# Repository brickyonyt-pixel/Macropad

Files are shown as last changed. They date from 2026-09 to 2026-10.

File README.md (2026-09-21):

# Macropad

A custom programmable macropad designed and built as part of my Hack Club Stardance project.

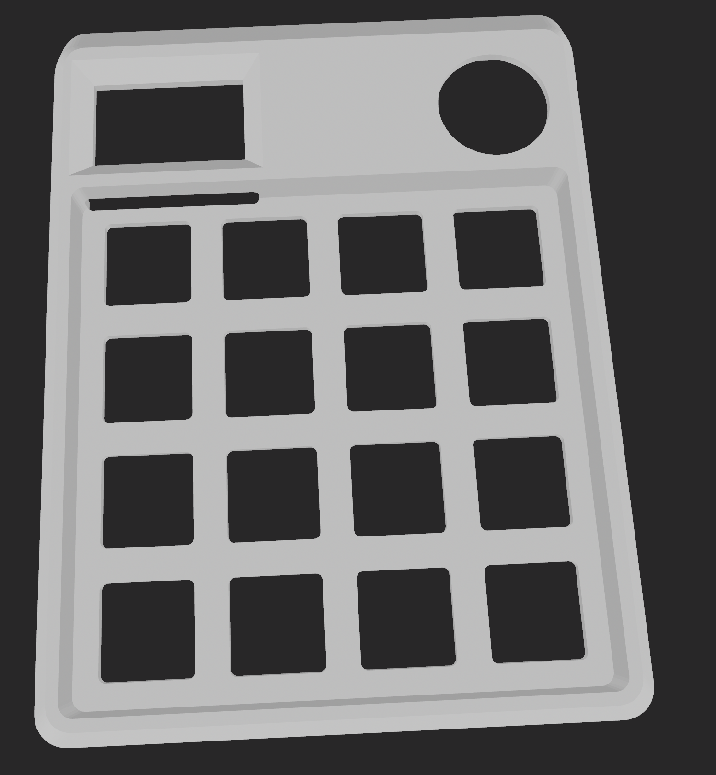
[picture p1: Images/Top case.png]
Macropad


## Overview

This project is a custom macropad designed to provide a compact way to use shortcuts and macros.

I designed the physical parts of the macropad around the PCB, including the top case, bottom case and knob. The project also includes the PCB, firmware, CAD files and manufacturing files required to build the macropad.

## Features

* Custom PCB
* Programmable keys
* Rotary knob
* USB connection
* Custom-designed case
* Custom firmware
* 3D-printed physical parts
* Manufacturing-ready PCB files
* STEP CAD files

## Design

The macropad is made up of several physical parts that fit together around the PCB. The top and bottom cases hold the electronics in place, while the knob provides an additional input.

### Top Case

Top Case

### Bottom Case

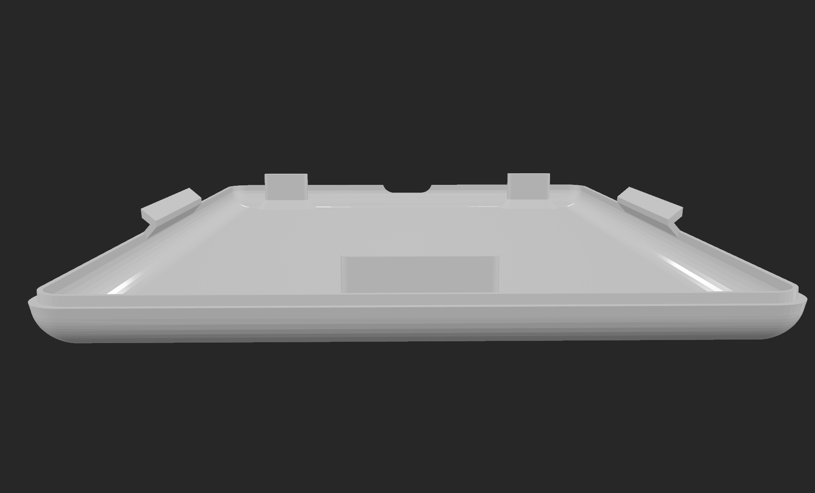
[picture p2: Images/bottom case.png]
Bottom Case


### Bottom of the Top Case

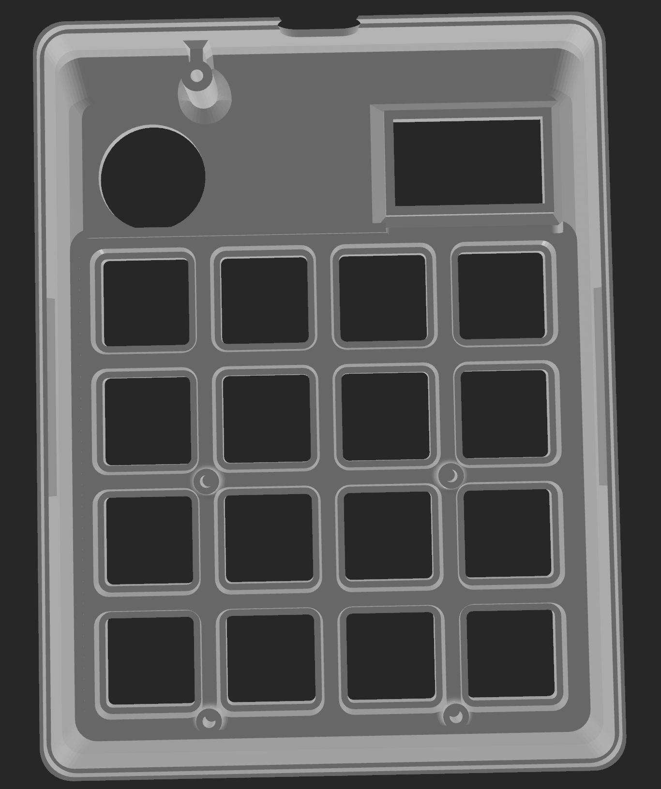
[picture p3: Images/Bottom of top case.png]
Bottom of Top Case


### PCB

The PCB contains the electronics used by the macropad and connects the different components together.

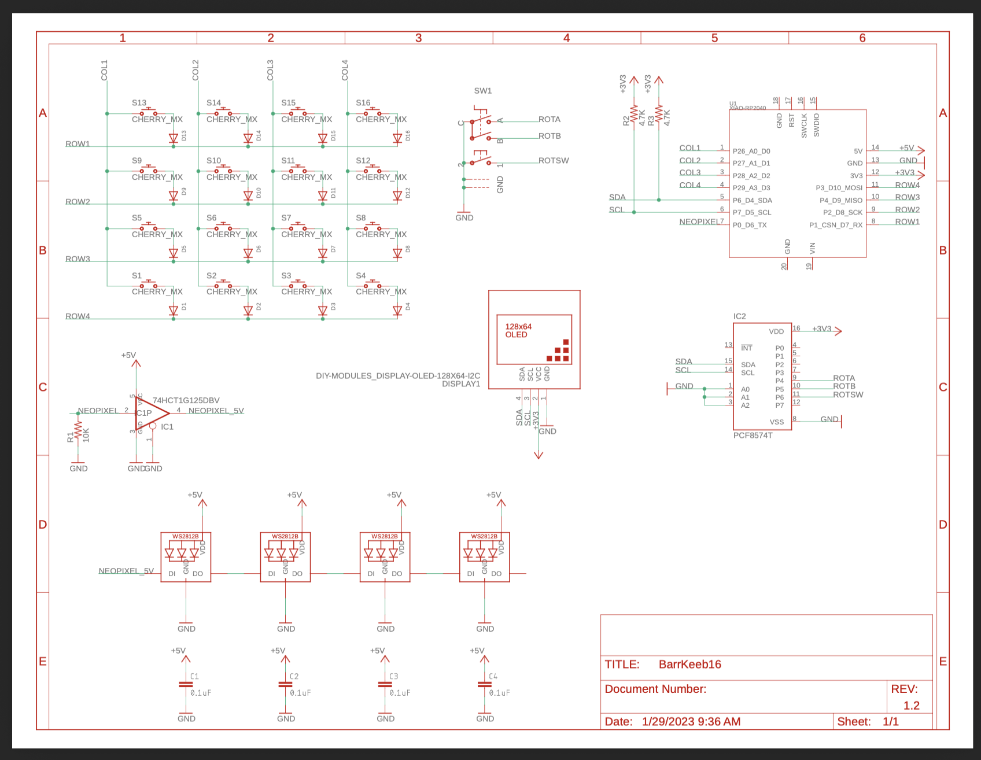
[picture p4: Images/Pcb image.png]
PCB


### Knob

The macropad also includes a rotary knob.

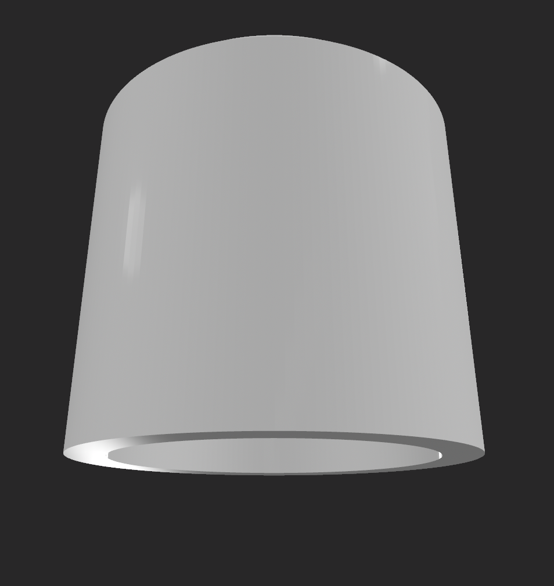
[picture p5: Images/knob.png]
Knob


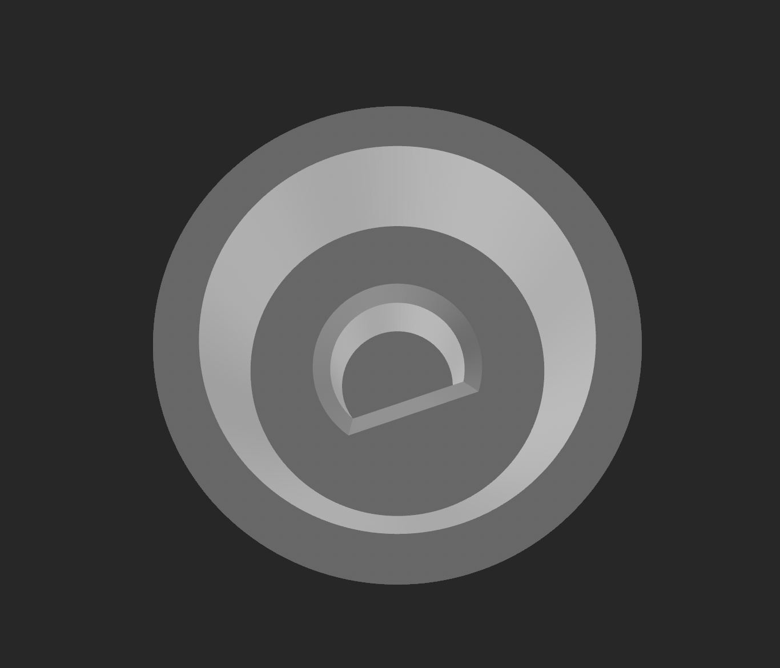
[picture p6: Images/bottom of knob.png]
Bottom of Knob


### Other Side of the Bottom Case

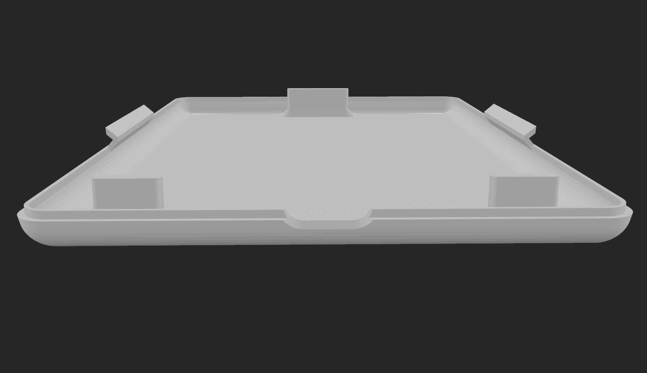
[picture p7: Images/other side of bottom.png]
Other Side of Bottom Case


## How It Works

When a key is pressed, the PCB detects the input and the microcontroller processes it. The firmware then sends the corresponding keyboard input to the computer through USB.

The rotary knob provides an additional input that can be programmed for different functions.

The PCB and physical case were designed to work together so that the components fit inside the finished macropad.

## Firmware

The firmware controls the behaviour of the macropad and allows it to communicate with a computer.

The production firmware is included in the `Macropad` folder.

## Production Files

The production files are stored inside the `Macropad` folder.

These include:

* Firmware
* CAD files
* Gerber files for PCB manufacturing
* Bill of Materials

The CAD files are provided in STEP format for the final production version.

## Bill of Materials

The Bill of Materials is included in the `Macropad` folder as `BOM.csv`.

It contains the components and quantities required to build the macropad.

## Development Journal

The development process is documented in [`Journal.md`](Journal.md).

The journal contains information about the development of the macropad and the work completed during the project.

## Repository Structure

```text
Macropad/
├── Images/
│   ├── Bottom of top case.png
│   ├── Pcb image.png
│   ├── Top case.png
│   ├── bottom case.png
│   ├── bottom of knob.png
│   ├── knob.png
│   └── other side of bottom.png
│
├── Macropad/
│   ├── BOM.csv
│   └── production/
│       ├── firmware/
│       ├── CAD/
│       └── gerber.zip
│
├── Journal.md
└── README.md
```

## Credits

Made by Aaran as part of Hack Club Stardance.

Thanks to Hack Club for providing Stardance and the resources that made this project possible.

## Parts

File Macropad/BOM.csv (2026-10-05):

Quantity | Part | Description | Link
1 | Custom PCB | Custom PCB | https://jlcpcb.com/
1 | Seeed XIAO RP2040 | Microcontroller | https://www.seeedstudio.com/XIAO-RP2040-v1-0-p-5026.html
16 | 1N4148W | Diode SOD-123 | https://www.digikey.ca/en/products/detail/smc-diode-solutions/1N4148W/6022450
16 | Cherry MX | MX-style switch | https://www.adafruit.com/product/5122
16 | DSA Keycap | DSA-style keycap | https://www.adafruit.com/product/4998
1 | PEC11R | Rotary encoder | https://www.adafruit.com/product/377
4 | SK6812/WS2812 | NeoPixel 5050 | https://www.digikey.ca/en/products/detail/adafruit-industries-llc/1655/5154679
4 | 0.1uF | 0603 capacitor | https://www.digikey.com/en/products/detail/samsung-electro-mechanics/CL10B104KB8NNNL/3894274
1 | 74AHCT1G125 | Level shifter | https://www.digikey.com/en/products/detail/texas-instruments/74AHCT1G125DBVTG4/1687957
1 | PCF8574T | IO expander | https://www.digikey.com/en/products/detail/nxp-usa-inc/PCF8574T-3-512/735690
1 | 10kΩ | 0805 resistor | https://www.digikey.com/en/products/detail/stackpole-electronics-inc/RMCF0805JG10K0/1757769
1 | 4.7kΩ | 0805 resistor | https://www.digikey.com/en/products/detail/stackpole-electronics-inc/RMCF0805JT4K70/1757774
5 | M2 x 2.5mm | Screw
4 | Rubber feet | Bumper feet | https://www.adafruit.com/product/550

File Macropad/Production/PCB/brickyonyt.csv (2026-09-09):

QTY | Value | Device | Package | Description | Digikey | QTY/Pack | Price | Link | Subtotal
4 | 0.1uF | 0.1UF-0603-25V-(+80/-20%) | 603 | 0.1µF ceramic capacitors | 276-CL10B104KB8NNNLCT-ND | 1 | 0.027 |  | 0.108
16 |  | MICROBUILDER_DIODESOD-123 | MICROBUILDER_SOD-123 | Diode | 1655-1360-1-ND | 1 | 0.124 |  | 1.984
1 | DIY-MODULES_DISPLAY-OLED-128X64-I2C | DIY-MODULES_DISPLAY-OLED-128X64-I2C | DIY-MODULES_DISPLAY-OLED-128X64-I2C | 128x64 Dot Matrix OLED Module based on SSD1306 chip | AOM12864A0-0.96WW-ANO | 1 | 1.35 | https://www.aliexpress.us/item/2251832770994631.html?_randl_shipto=US | 1.35
1 | 74HCT1G125DBV | 74AHC1G125DBV | SOT23-5 | Single Bus Buffer Gate with 3-State Output | 296-49526-1-ND | 1 | 0.95 |  | 0.95
1 | PCF8574T | PCF8574T | SO16W | I2C-Bus Remote 8-bit I/O expander | 568-1076-5-ND | 1 | 1.86 |  | 1.86
4 | WS2812B5050 | WS2812B5050 | WS2812B | NeoPixel 5050 RGB LED | 1528-2386-ND | 10 | 4.5 |  | 4.5
2 | 10K | R-US_R0805 | R0805 | RESISTOR, American symbol | RMCF0805JG10K0CT-ND | 1 | 0.018 |  | 0.036
1 | 4.7K | R-US_R0805 | R0805 | RESISTOR, American symbol | RMCF0805JG4K70CT-ND | 1 | 0.018 |  | 0.018
16 | CHERRY_MX | CHERRY_MX | CHERRY_MX | Cherry keymodule MX | 1528-4952-ND | 10 | 0.88 | https://www.aliexpress.us/item/3256803506501651.html?_randl_shipto=US | 1.76
1 |  | ADAFRUIT_ELECTROMECH_ENCODER_PLUS_SWITCH_BOURNS_PEC11 | ADAFRUIT_ELECTROMECH_PEC11+SWITCH | Rotary Encoder with Built-In Switch | PEC11R-4215F-S0024-ND | 1 | 1.88 |  | 1.88
1 | XIAO-RP2040 | XIAO-RP2040 | XIAO-SAMD21/RP2040-MODULE14P-2.54-21X17.8MM | Seeed Studio XIAO RP2040 v1.22 - Raspberry Pi RP2040 Microcontroller - 32-bit 133MHz Dual-Core ARM® Cortex® M0+processor Seeed SKU: 102010428 | 1597-102010428-ND | 1 | 5.4 | https://www.seeedstudio.com/XIAO-RP2040-v1-0-p-5026.html | 5.4
 |  |  |  |  |  |  |  | Total | 19.846

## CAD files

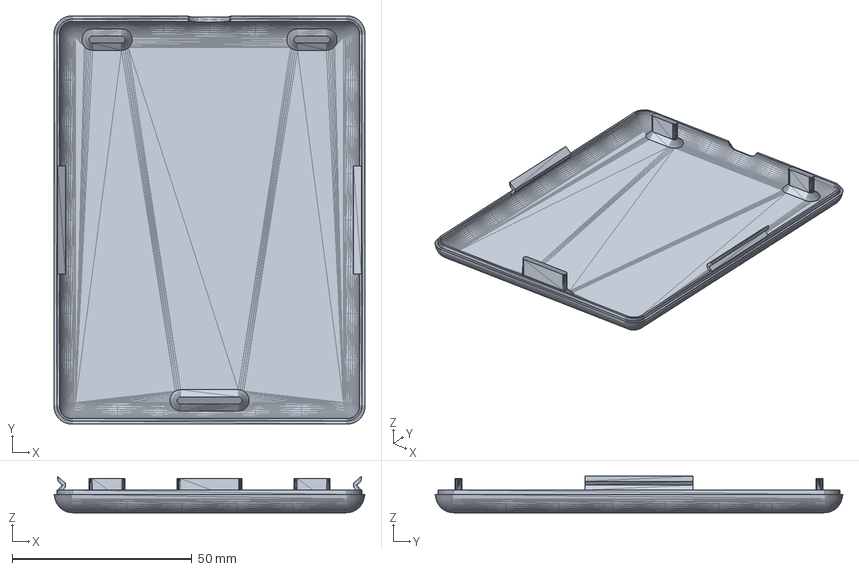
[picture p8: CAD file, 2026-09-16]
Macropad/Production/Models/brickyonyt_Bottom_Case.step
86.4 x 113.4 x 10.1 mm

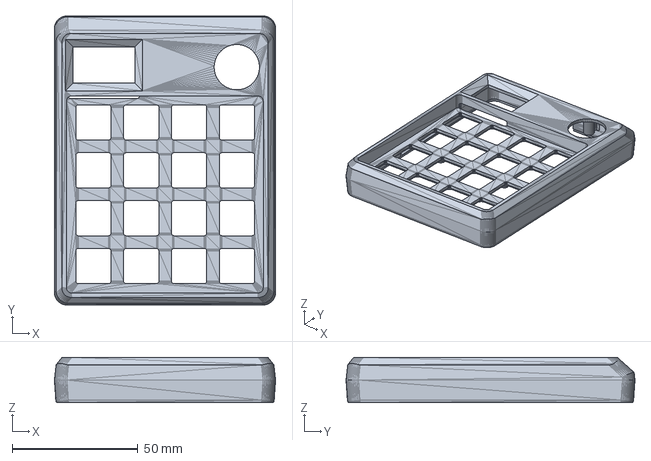
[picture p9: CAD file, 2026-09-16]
Macropad/Production/Models/brickyonyt_Top_Case.step
88.0 x 115.0 x 18.0 mm

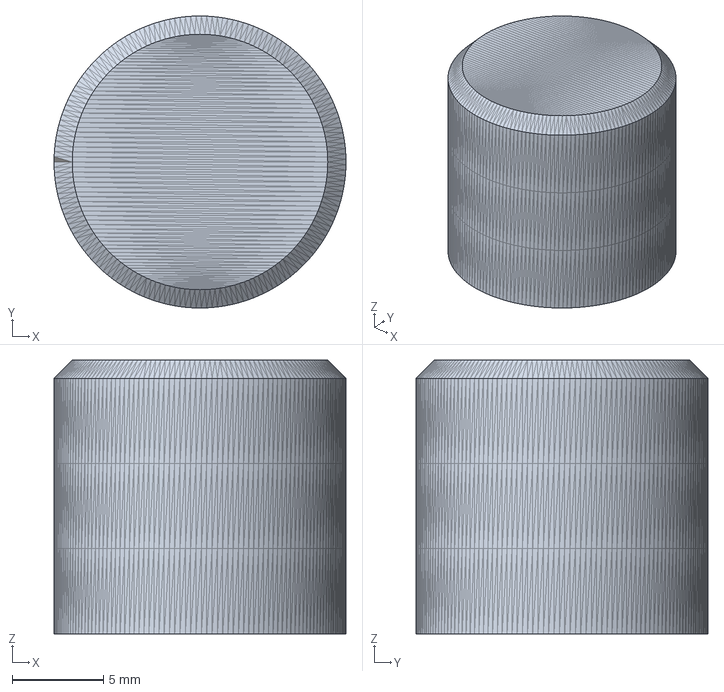
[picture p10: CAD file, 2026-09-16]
Macropad/Production/Models/Knob.step
16.0 x 16.0 x 15.0 mm

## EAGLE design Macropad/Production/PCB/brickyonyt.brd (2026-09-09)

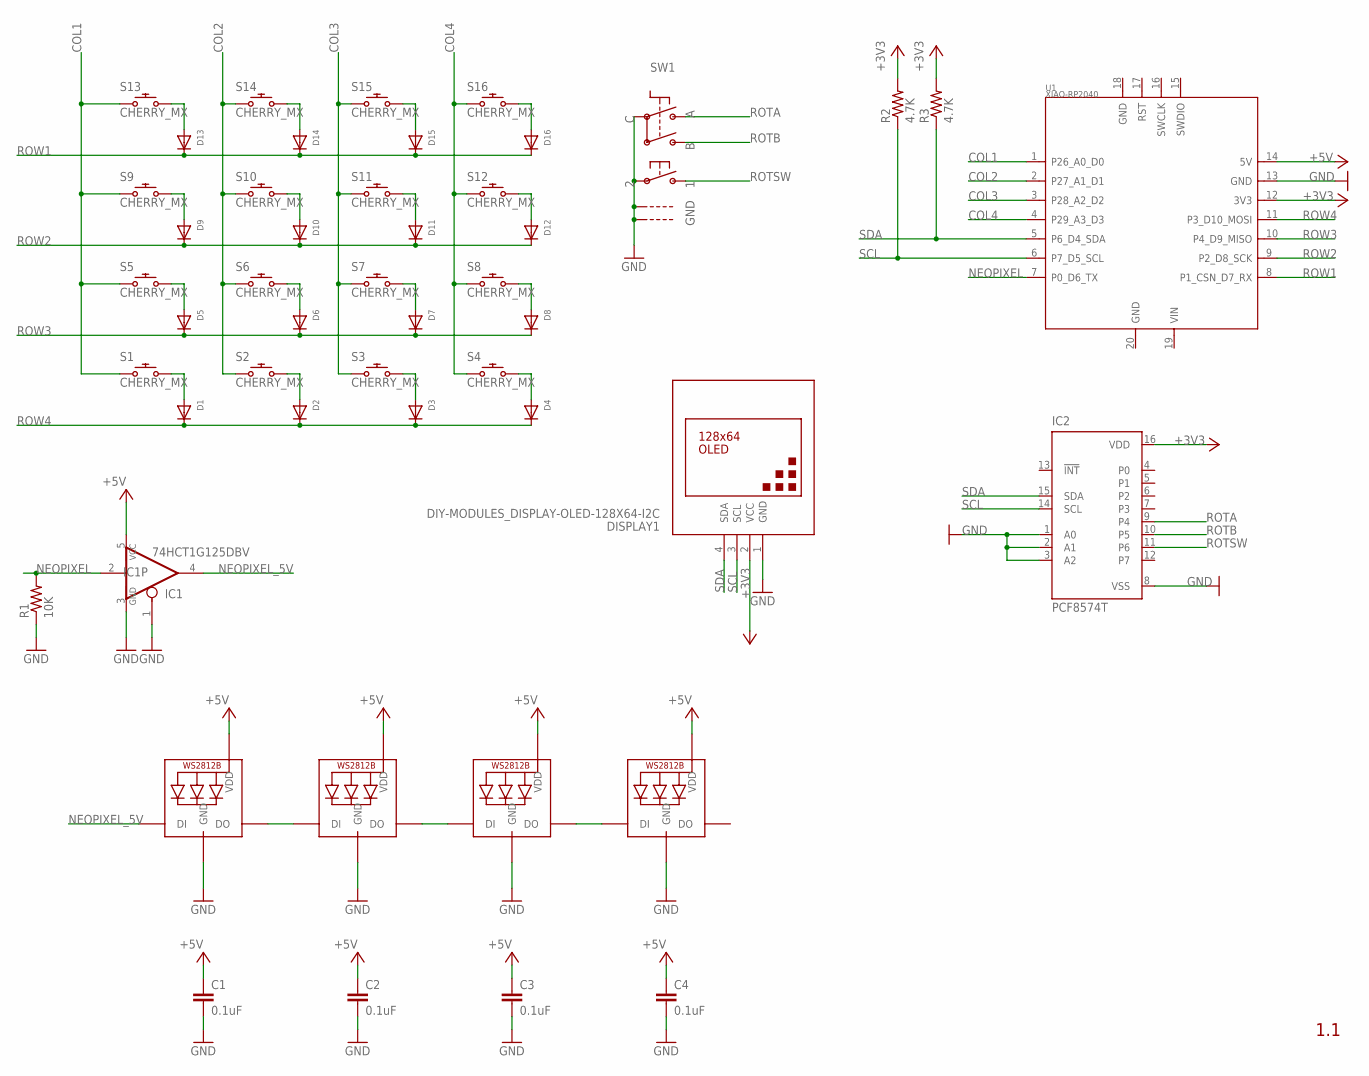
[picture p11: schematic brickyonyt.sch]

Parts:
C1, C2, C3, C4: 0.1uF; 0603
D1, D2, D3, D4, D5, D6, D7, D8, D9, D10, D11, D12, D13, D14, D15, D16: MICROBUILDER_DIODESOD-123; MICROBUILDER_SOD-123
DISPLAY1: DIY-MODULES_DISPLAY-OLED-128X64-I2C
IC1: 74HCT1G125DBV; SOT23-5
IC2: PCF8574T; SO16W
LED1, LED2, LED3, LED4: WS2812B5050; WS2812B
R1: 10K; R0805
R2, R3: 4.7K; R0805
S1, S2, S3, S4, S5, S6, S7, S8, S9, S10, S11, S12, S13, S14, S15, S16: CHERRY_MX
SW1: ADAFRUIT_ELECTROMECH_ENCODER_PLUS_SWITCH_BOURNS_P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; ADAFRUIT_ELECTROMECH_PEC11+SWITCH
U1: XIAO-RP2040; XIAO-SAMD21/RP2040-MODULE14P-2.54-21X17.8MM

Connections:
+3V3: DISPLAY1.2 (VCC), IC2.16 (VDD), R2.2, R3.2, U1.12 (3V3)
+5V: C1.1, C2.1, C3.1, C4.1, IC1.5 (VCC), LED1.1-VDD (VDD), LED2.1-VDD (VDD), LED3.1-VDD (VDD), LED4.1-VDD (VDD), U1.14 (5V)
COL1: S1.S1 (1), S5.S1 (1), S9.S1 (1), S13.S1 (1), U1.1 (P26_A0_D0)
COL2: S2.S1 (1), S6.S1 (1), S10.S1 (1), S14.S1 (1), U1.2 (P27_A1_D1)
COL3: S3.S1 (1), S7.S1 (1), S11.S1 (1), S15.S1 (1), U1.3 (P28_A2_D2)
COL4: S4.S1 (1), S8.S1 (1), S12.S1 (1), S16.S1 (1), U1.4 (P29_A3_D3)
GND: C1.2, C2.2, C3.2, C4.2, DISPLAY1.1 (GND), IC1.1 (OE), IC1.3 (GND), IC2.1 (A0), IC2.2 (A1), IC2.3 (A2), IC2.8 (VSS), LED1.3-GND (GND), LED2.3-GND (GND), LED3.3-GND (GND), LED4.3-GND (GND), R1.1, SW1.P$2, SW1.P$C, SW1.P$GND1, SW1.P$GND2, U1.13 (GND)
unnamed: D13.A, S13.S2 (2)
unnamed: D14.A, S14.S2 (2)
unnamed: LED1.2-DOUT (DO), LED2.4-DIN (DI)
unnamed: LED2.2-DOUT (DO), LED3.4-DIN (DI)
unnamed: LED3.2-DOUT (DO), LED4.4-DIN (DI)
unnamed: D15.A, S15.S2 (2)
unnamed: D16.A, S16.S2 (2)
unnamed: D9.A, S9.S2 (2)
unnamed: D10.A, S10.S2 (2)
unnamed: D11.A, S11.S2 (2)
unnamed: D12.A, S12.S2 (2)
unnamed: D5.A, S5.S2 (2)
unnamed: D6.A, S6.S2 (2)
unnamed: D7.A, S7.S2 (2)
unnamed: D8.A, S8.S2 (2)
unnamed: D1.A, S1.S2 (2)
unnamed: D2.A, S2.S2 (2)
unnamed: D3.A, S3.S2 (2)
unnamed: D4.A, S4.S2 (2)
NEOPIXEL: IC1.2 (I), R1.2, U1.7 (P0_D6_TX)
NEOPIXEL_5V: IC1.4 (O), LED1.4-DIN (DI)
ROTA: IC2.9 (P4), SW1.P$A
ROTB: IC2.10 (P5), SW1.P$B
ROTSW: IC2.11 (P6), SW1.P$1
ROW1: D13.C, D14.C, D15.C, D16.C, U1.8 (P1_CSN_D7_RX)
ROW2: D9.C, D10.C, D11.C, D12.C, U1.9 (P2_D8_SCK)
ROW3: D5.C, D6.C, D7.C, D8.C, U1.10 (P4_D9_MISO)
ROW4: D1.C, D2.C, D3.C, D4.C, U1.11 (P3_D10_MOSI)
SCL: DISPLAY1.3 (SCL), IC2.14 (SCL), R2.1, U1.6 (P7_D5_SCL)
SDA: DISPLAY1.4 (SDA), IC2.15 (SDA), R3.1, U1.5 (P6_D4_SDA)

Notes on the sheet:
1.1

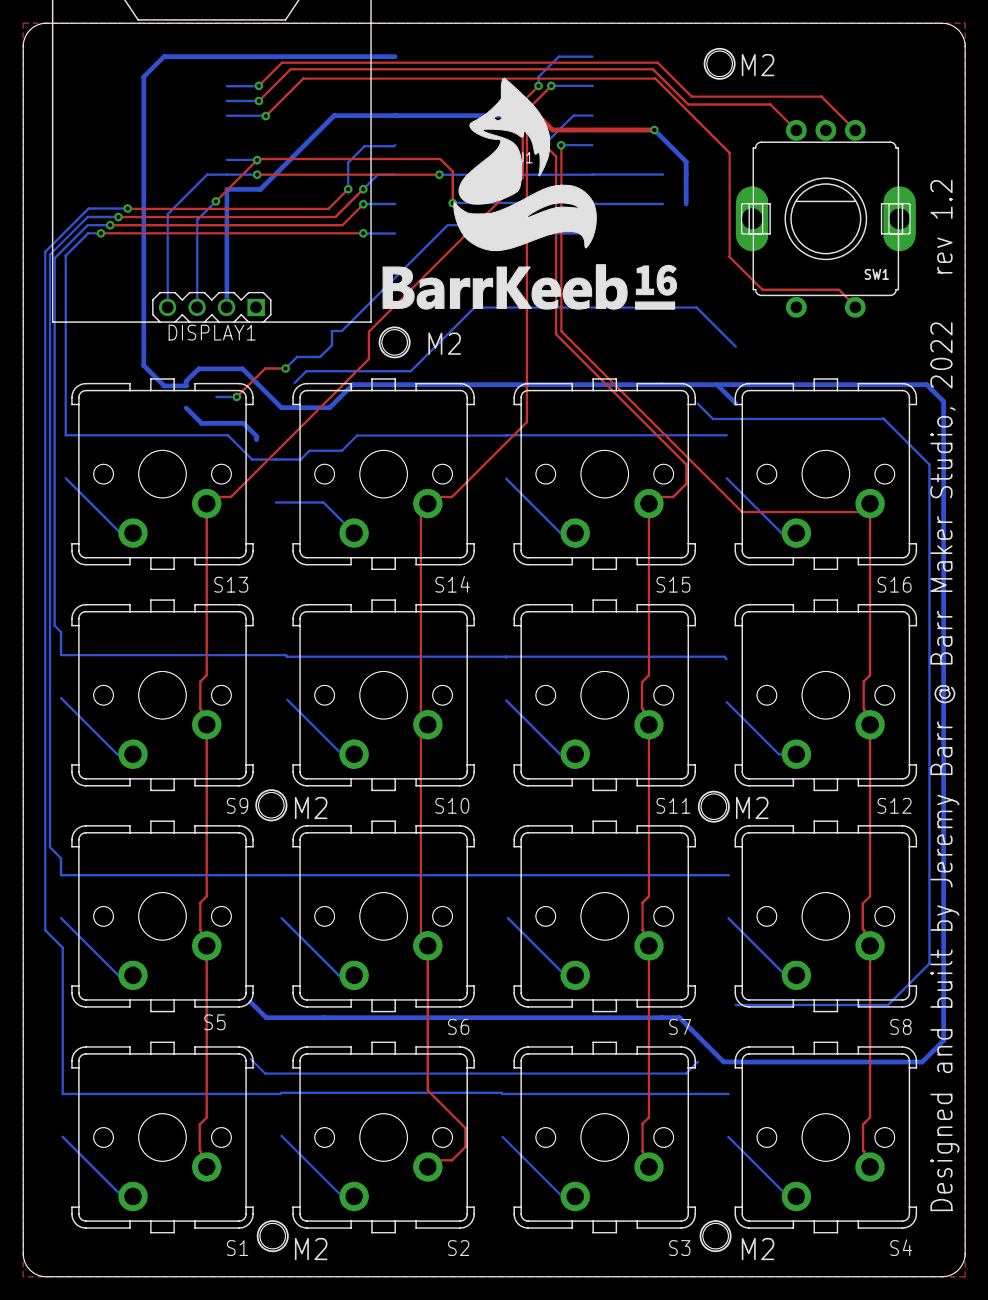
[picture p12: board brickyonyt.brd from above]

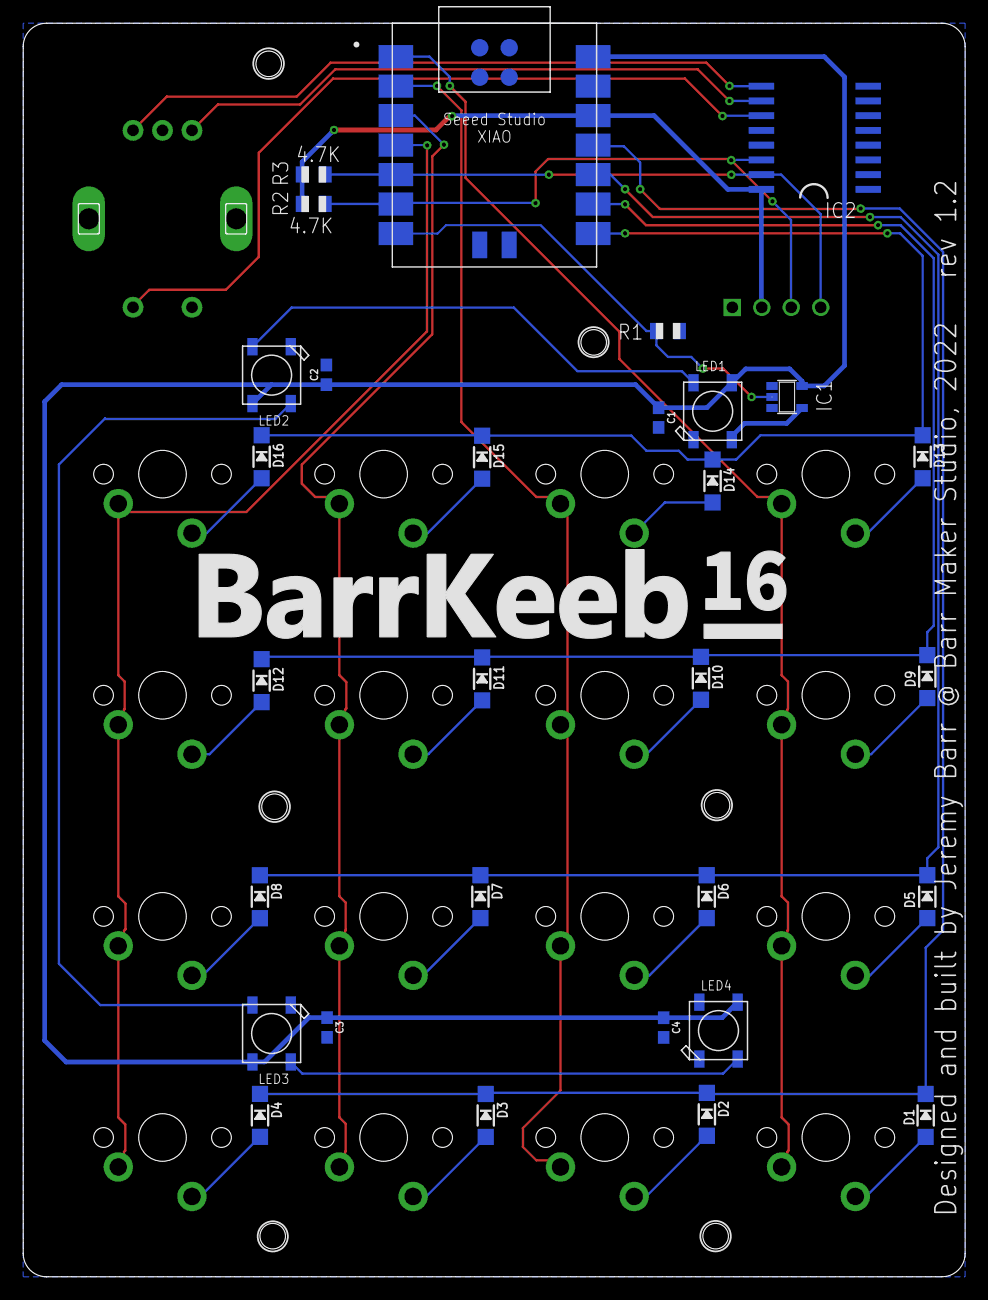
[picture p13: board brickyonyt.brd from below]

Board: 2 copper layers, 81.2 x 108.0 mm, 50 parts (31 on the bottom side), 37 nets.

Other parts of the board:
U$1: BARRKEEP16-LOGO
U$2: BARRKEEB-16

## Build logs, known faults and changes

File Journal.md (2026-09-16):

Development Journal

Project Start:
I started this project as a Hack Club Stardance project to design and build my own macropad. I wanted to make a small custom keyboard with my own PCB, CAD and firmware.

Initial Design:
I started with the overall macropad layout and decided where the keys and other components would go. I also started working on the PCB design and the physical enclosure.

PCB Design:
I worked on the schematic and PCB layout, ensuring the components were connected correctly and that the board layout matched the physical design.

CAD:
I designed the physical parts of the macropad and checked that the enclosure and PCB would fit together. I later prepared the CAD files for manufacturing and made sure the final files were available in STEP format.

Firmware:
I worked on the firmware needed to make the macropad function as an input device.

Testing and Changes:
During the project I checked the different parts of the design and made changes where necessary. I also checked that the PCB, CAD and firmware worked together as one project.

Preparing for Production:
After finishing the main design, I organised the files needed to manufacture and build the macropad. This included the PCB Gerber files, CAD files, firmware and bill of materials.

Finalising the Project:
I organised the GitHub repository so that the important project files are easier to find. I also added documentation and pictures of the PCB and CAD to the README.

Stardance Submission:
I prepared the project for Stardance review and went through the repository requirements. I added the remaining documentation and production files so the project could be properly reviewed and reproduced.

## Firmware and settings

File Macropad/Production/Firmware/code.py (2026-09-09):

######################
#  BrickyOnYT
#  version 1.0
#  28-Dec-2022
#  Author: Aaran
#
#  Notes:
#  kmk.matrix modified for PCF8574 output LOW when polling columns.
#  PCF8574 modified to read pin value as opposite value. KMK reads pin HIGH as keypress, but that's default input value.
######################

#print("Starting")

import board
import displayio

import adafruit_pcf8574  # modded library to work with KMK
import adafruit_displayio_ssd1306

import terminalio
import neopixel
from adafruit_display_text import label
from display_logo import display_splash_fox_inverted

from kmk.kmk_keyboard import KMKKeyboard
from kmk.keys import KC
from kmk.matrix import DiodeOrientation
from kmk.handlers.sequences import send_string, simple_key_sequence
from kmk.modules.layers import Layers as _Layers
from kmk.modules.encoder import EncoderHandler
from kmk.modules.tapdance import TapDance
from kmk.extensions.media_keys import MediaKeys
from kmk.extensions.RGB import RGB

# init IO Expander
pcf = adafruit_pcf8574.PCF8574(board.I2C(), address=0x20)

# KEYBOARD SETUP
#layers = Layers()
keyboard = KMKKeyboard()
encoders = EncoderHandler()
tapdance = TapDance()
tapdance.tap_time = 250
keyboard.modules = [encoders, tapdance]

# SWITCH MATRIX
keyboard.col_pins = (pcf.get_pin(4), pcf.get_pin(5), pcf.get_pin(6), pcf.get_pin(7))
keyboard.row_pins = (pcf.get_pin(0), pcf.get_pin(1), pcf.get_pin(2), pcf.get_pin(3))
keyboard.diode_orientation = DiodeOrientation.ROWS

# ENCODERS
encoders.pins = ((board.A0, board.A1, board.A2, False),)

# EXTENSIONS
rgb_ext = RGB(pixel_pin = board.D3, num_pixels=4)#, hue_default=100)
keyboard.extensions = [rgb_ext, MediaKeys()]

# custom functions
class Layers(_Layers):
    last_top_layer = 0
    hues = (4, 20, 69)
    
    def after_hid_send(keyboard):
        print(keyboard.active_layers[0])
        if keyboard.active_layers[0] != self.last_top_layer:
            self.last_top_layer = keyboard.active_layers[0]
            rgb.set_hsv_fill(self.hues[self.last_top_layer], 255, 255)
            display_layer_text(keyboard.active_layers[0])
            #print(keyboard.active_layers[0])
            
keyboard.modules.append(Layers())

keyboard.debug_enabled = False

# MACROS Layer 1
WIN_RIGHT = simple_key_sequence([KC.LGUI(KC.RIGHT), KC.MACRO_SLEEP_MS(100), KC.ESC])
WIN_LEFT = simple_key_sequence([KC.LGUI(KC.LEFT), KC.MACRO_SLEEP_MS(100), KC.ESC])
WIN_UP = simple_key_sequence([KC.LGUI(KC.UP)])
WIN_MIN = simple_key_sequence([KC.LGUI(KC.M)])
WIN_MAX = simple_key_sequence([KC.LGUI(KC.LSFT(KC.M))])
DESK_RIGHT = simple_key_sequence([KC.LCMD(KC.LCTRL(KC.RIGHT))])
DESK_LEFT = simple_key_sequence([KC.LCMD(KC.LCTRL(KC.LEFT))])
WIN_TAB = simple_key_sequence([KC.LCMD(KC.TAB)])
COPY = KC.LCTRL(KC.C)
PASTE = KC.LCTRL(KC.V)
POWERSHELL = simple_key_sequence([KC.LCMD(KC.R), KC.MACRO_SLEEP_MS(250), send_string('powershell'), KC.ENTER])

# NEOPIXEL RGB
#RGB_COLORS = KC.TD(Color.RED, Color.GREEN, Color.BLUE, Color.WHITE, Color.YELLOW, Color.ORANGE)
#TODO: change to NEOPIXEL functions
# Color_RED = rgb_ext.set_hsv_fill(0,100,100)
# Color_BLUE = rgb_ext.set_hsv_fill(240,100,100)
# Color_MAGENTA = rgb_ext.set_hsv_fill(300,100,100)
# Color_ORANGE = rgb_ext.set_hsv_fill(30,100,100)
# Color_WHITE = rgb_ext.set_hsv_fill(0,0,100)
# Color_GREEN = rgb_ext.set_hsv_fill(120,100,100)

_______ = KC.TRNS
xxxxxxx = KC.NO

# LAYER SWITCHING TAP DANCE
#TD_LYRS_1 = KC.TD(KC.KP_ENTER, KC.TO(1), KC.TO(2), KC.TO(0))
TD_LYRS_0 = KC.TD(KC.KP_ENTER, KC.TO(0))
TD_LYRS_1 = KC.TD(KC.KP_ENTER, KC.TO(1))
TD_LYRS_2 = KC.TD(KC.KP_ENTER, KC.TO(2))
RGB_LYRS = KC.TD(KC.RGB_MODE_PLAIN, KC.RGB_MODE_SWIRL, KC.RGB_MODE_KNIGHT, KC.RGB_MODE_RAINBOW, KC.RGB_MODE_BREATHE_RAINBOW)

# KEYMAPS
keyboard.keymap = [
    [  # Layer 0: WIN MACROS
        TD_LYRS_1, POWERSHELL,   WIN_TAB,    RGB_LYRS,
        WIN_UP,    KC.MPRV,      KC.MNXT,    KC.MPLY,
        WIN_LEFT,  WIN_RIGHT,    WIN_MIN,    WIN_MAX,
        COPY,      PASTE,        DESK_LEFT,  DESK_RIGHT ,
    ],
    [  # Layer 1: NUMPAD
        TD_LYRS_2,   KC.KP_SLASH,   KC.KP_ASTERISK,   KC.KP_MINUS,
        KC.P7,       KC.P8,         KC.P9,            KC.KP_PLUS,
        KC.P4,       KC.P5,         KC.P6,            KC.PDOT,
        KC.P1,       KC.P2,         KC.P3,            KC.P0,
    ],
    [  # Layer 2: RGB CTL
        TD_LYRS_0,          KC.RGB_HUI,          KC.RGB_VAI,                   KC.RGB_ANI,
        KC.RGB_SAI,         KC.RGB_HUD,          KC.RGB_VAD,                   KC.RGB_AND,    
        KC.RGB_MODE_SWIRL,  KC.RGB_MODE_KNIGHT,  KC.RGB_MODE_BREATHE_RAINBOW,  KC.RGB_SAI,
        KC.RGB_MODE_PLAIN,  KC.RGB_MODE_BREATHE, KC.RGB_MODE_RAINBOW,          KC.RGB_SAD,    
    ],
]

encoders.map = [    ((KC.VOLD, KC.VOLU, KC.MUTE),),   # MEDIA
                    ((KC.VOLD, KC.VOLU, KC.MUTE),),   # MEDIA
                    ((KC.RGB_AND, KC.RGB_ANI, KC.RGB_TOG),),   # RGB
                ]

#print("Keyboard Go!")
display_splash_fox_inverted()
if __name__ == '__main__':
    keyboard.go()

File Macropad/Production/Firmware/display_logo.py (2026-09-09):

import board
import time
import displayio
import adafruit_displayio_ssd1306

displayio.release_displays()

SCREEN_WIDTH = 128 # OLED display width, in pixels
SCREEN_HEIGHT = 64 # OLED display height, in pixels

# Create the OLED display object
display = adafruit_displayio_ssd1306.SSD1306(
    displayio.I2CDisplay(board.I2C(), device_address=0x3C),
    width=SCREEN_WIDTH,
    height=SCREEN_HEIGHT,
    rotation=180
)

def display_splash_fox():
    # Create a new display group
    group = displayio.Group()
    
    # Create a bitmap from the image file
    bitmap = displayio.OnDiskBitmap('Name.bmp')
    
    # Create a palette with 2 colors (black and white)
    palette = displayio.Palette(2)
    palette[0] = 0x000000
    palette[1] = 0xFFFFFF

    # Create a TileGrid to hold the bitmap
    color_converter = displayio.ColorConverter()
    tilegrid = displayio.TileGrid(bitmap, pixel_shader=bitmap.pixel_shader)
    # Add the tilegrid to the group
    group.append(tilegrid)

    # Set the group as the display's root
    display.show(group)
    #print("Display Logo")

def display_splash_fox_inverted():
    # Create a new display group
    group = displayio.Group()
    
    # Create a bitmap from the image file
    bitmap = displayio.OnDiskBitmap('Name Inverted.bmp')
    
    # Create a palette with 2 colors (black and white)
    palette = displayio.Palette(2)
    palette[0] = 0x000000
    palette[1] = 0xFFFFFF

    # Create a TileGrid to hold the bitmap
    color_converter = displayio.ColorConverter()
    tilegrid = displayio.TileGrid(bitmap, pixel_shader=bitmap.pixel_shader)
    # Add the tilegrid to the group
    group.append(tilegrid)

    # Set the group as the display's root
    display.show(group)
    #print("Display Logo Inverted")

def display_layer_text(layer):
    displaytext= {0:"Layer 0",1:"Layer 1",2:"Layer 2"}
    return displaytext.get(layer, "no layer")

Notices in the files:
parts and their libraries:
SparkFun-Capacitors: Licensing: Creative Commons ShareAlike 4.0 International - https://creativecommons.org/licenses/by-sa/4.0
